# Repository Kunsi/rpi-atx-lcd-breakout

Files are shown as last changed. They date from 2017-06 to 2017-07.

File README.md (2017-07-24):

# RPi-ATX-LCD-Breakout

This board allows you to connect an ATX power supply and a HD44780-compatible LCD
screen to your Raspberry Pi (or others with compatible GPIO layout).

While it does have a 40pin GPIO connector, it will also work with older 
26-pin variants of the Pi.

The board was created to provide a convenient interface for two
[Octoprint](http://octoprint.org/) plugins:
[PSUControl](https://github.com/kantlivelong/OctoPrint-PSUControl) and
[LCD-HD44780](https://github.com/Kunsi/Octoprint-LCD-HD44780) (See links on
bottom of this page).

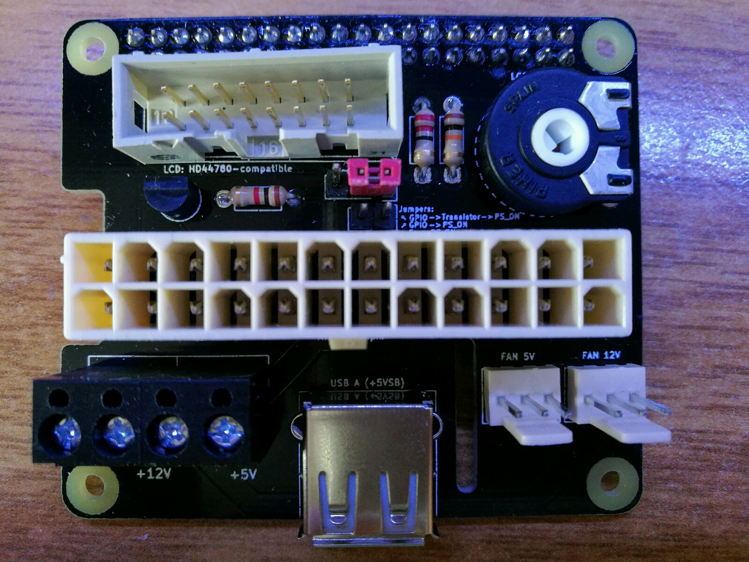
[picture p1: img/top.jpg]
Board


The board itself offers a variety of features:
* Powering the Pi using +5VSB (standby power)
* Switching the PSU on and off using GPIO pin 12
  
  The GPIO pin can be connected to PS_ON directly, or via a transistor. This is
  choosable using the three-pin jumper switch.

  Alternatively, the PSU can be forced to be on, by using the 2-pin PS_ON
  jumper.
* Providing a "is the PSU on"-detection by wiring GPIO pin 11 to the 3v3 rail
  of the PSU
* Connecting a character LCD to the Pi
  
  LCD is wired as follows:
  <dl>
    <dt>Register Select</dt>
    <dd>15</dd>

    <dt>Enable</dt>
    <dd>16</dd>

    <dt>Data 4</dt>
    <dd>21</dd>

    <dt>Data 5</dt>
    <dd>22</dd>

    <dt>Data 6</dt>
    <dd>23</dd>

    <dt>Data 7</dt>
    <dd>24</dd>
  </dl>

  Data 0-3 pins are not connected. Read/Write select has been wired to GND, so
  it's not possible to read data from the LCD screen. Contrast pin is
  connected to a potentiometer.
* Allow connecting of two fans, one 5V, one 12V
* Providing screw terminals for GND, +12V, +5VSB and +5V
* Providing a USB outlet powered by +5VSB

Note: All pin numbers use BOARD numbering.

## Cost
Prices are in Euro, and are based on my prototype production cost

Item            | Count    | Price | Link
----------------|---------:|------:|---
PCB             | 1        | 1.70  | [PCBway](https://www.pcbway.com/) got me 10 boards for 17$
Fan connector   | 2        | 0.42  | <https://www.reichelt.de/?ARTICLE=185658>
Pin header      | 3+2 wide | 0.09  | <https://www.reichelt.de/?ARTICLE=119891>
Potentiometer   | 1        | 0.38  | <https://www.reichelt.de/?ARTICLE=14951>
LCD connector   | 1        | 0.52  | <https://www.reichelt.de/?ARTICLE=175351>
Screw terminals | 2        | 0.42  | <https://www.reichelt.de/?ARTICLE=170222>
Jumper          | 1        | 0.03  | <https://www.reichelt.de/?ARTICLE=119944>
USB connector   | 1        | 0.20  | <https://www.reichelt.de/?ARTICLE=22184>
Transistor      | 1        | 0.09  | <https://www.reichelt.de/?ARTICLE=1999>
Resistors       | 1+1+1    | 0.30  | <https://www.reichelt.de/?ARTICLE=1381><br> <https://www.reichelt.de/?ARTICLE=1315><br> <https://www.reichelt.de/?ARTICLE=1338>
GPIO connector  | 1        | 0.11  | [https://de.aliexpress.com/…/32454935478.html](https://de.aliexpress.com/item/100pcs-lot-2-54mm-Double-Row-Female-12P-Straight-Header-Pitch-Socket-Strip-2X20-Pin/32454935478.html)
ATX connector   | 1        | 0.43  | <http://www.mouser.de/ProductDetail/TE-Connectivity/1-1775099-3/>

## Links
* [Octoprint](http://octoprint.org/)
* [OctoPrint-PSUControl](https://github.com/kantlivelong/OctoPrint-PSUControl) by kantlivelong
* [Octoprint-LCD-HD44780](https://github.com/Kunsi/Octoprint-LCD-HD44780) by Kunsi

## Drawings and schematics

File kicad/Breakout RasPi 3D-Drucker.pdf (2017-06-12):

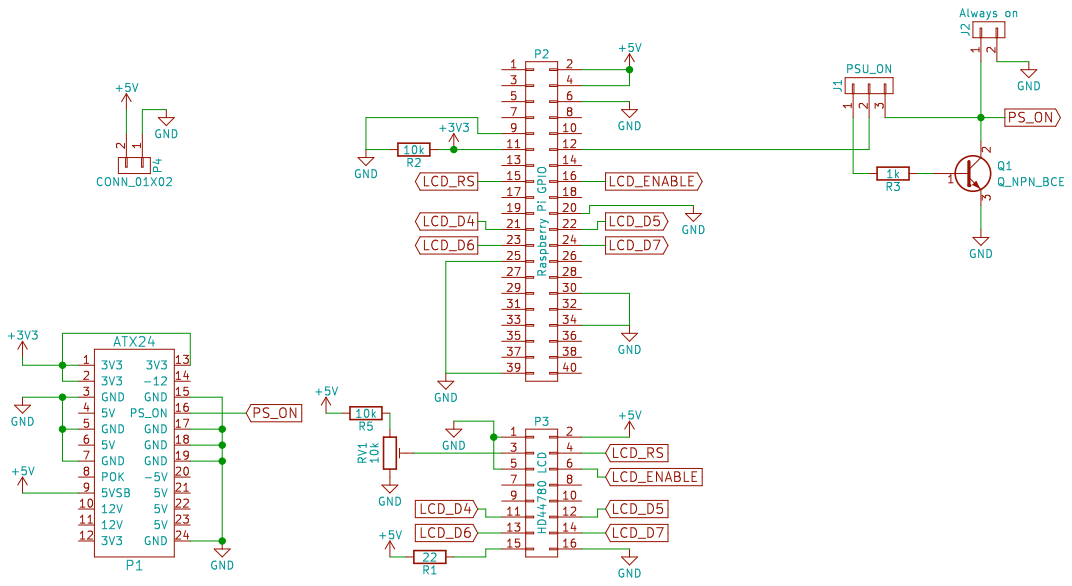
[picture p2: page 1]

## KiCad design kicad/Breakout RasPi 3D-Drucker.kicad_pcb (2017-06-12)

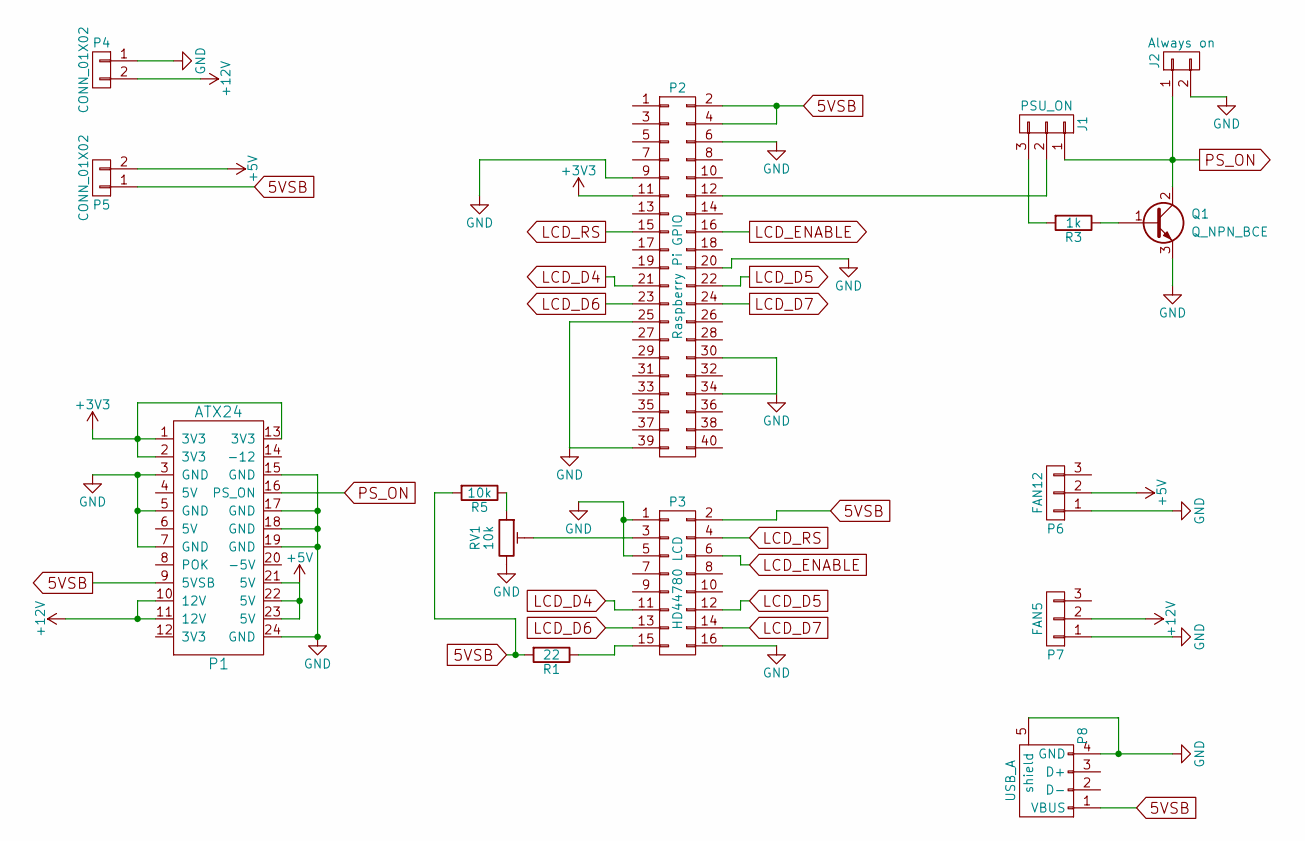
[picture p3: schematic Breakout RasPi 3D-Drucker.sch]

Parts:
J1: PSU_ON; Pin_Header_Straight_1x03
J2: Always on; Pin_Header_Straight_1x02
P1: ATX24
P2: Raspberry Pi GPIO; Socket_Strip_Straight_2x20
P3: HD44780 LCD; IDC_Header_Straight_16pins
P4, P5: CONN_01X02; RND_205-00001
P6: FAN12; Molex_KK-6410-03_03x2.54mm_Straight
P7: FAN5; Molex_KK-6410-03_03x2.54mm_Straight
P8: USB_A
Q1: Q_NPN_BCE; TO-92_Inline_Narrow_Oval
R1: 22; Resistor_Horizontal_RM7mm
R3: 1k; Resistor_Horizontal_RM7mm
R5: 10k; Resistor_Horizontal_RM7mm
RV1: 10k; Potentiometer_Trimmer-Piher_PT15-V12-5_horizontal_revers

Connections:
5VSB: P1.9 (5VSB), P2.2, P2.4, P3.2, P5.1, P8.1 (VBUS), R1.2, R5.2
+3V3: P1.1 (3V3), P1.2 (3V3), P1.13 (3V3), P2.11
+5V: P1.21 (5V), P1.22 (5V), P1.23 (5V), P5.2, P6.2
+12V: P1.10 (12V), P1.11 (12V), P4.2, P7.2
GND: J2.2, P1.3 (GND), P1.5 (GND), P1.7 (GND), P1.15 (GND), P1.17 (GND), P1.18 (GND), P1.19 (GND), P1.24 (GND), P2.6, P2.9, P2.20, P2.25, P2.30, P2.34, P2.39, P3.1, P3.5, P3.16, P4.1, P6.1, P7.1, P8.4 (GND), P8.5 (shield), Q1.3 (E), RV1.3
LCD_D4: P2.21, P3.11
LCD_D5: P2.22, P3.12
LCD_D6: P2.23, P3.13
LCD_D7: P2.24, P3.14
LCD_ENABLE: P2.16, P3.6
LCD_RS: P2.15, P3.4
unnamed: J1.2, P2.12
unnamed: J1.3, R3.2
unnamed: P3.3, RV1.2
unnamed: P3.15, R1.1
unnamed: Q1.1 (B), R3.1
unnamed: R5.1, RV1.1
PS_ON: J1.1, J2.1, P1.16 (PS_ON), Q1.2 (C)

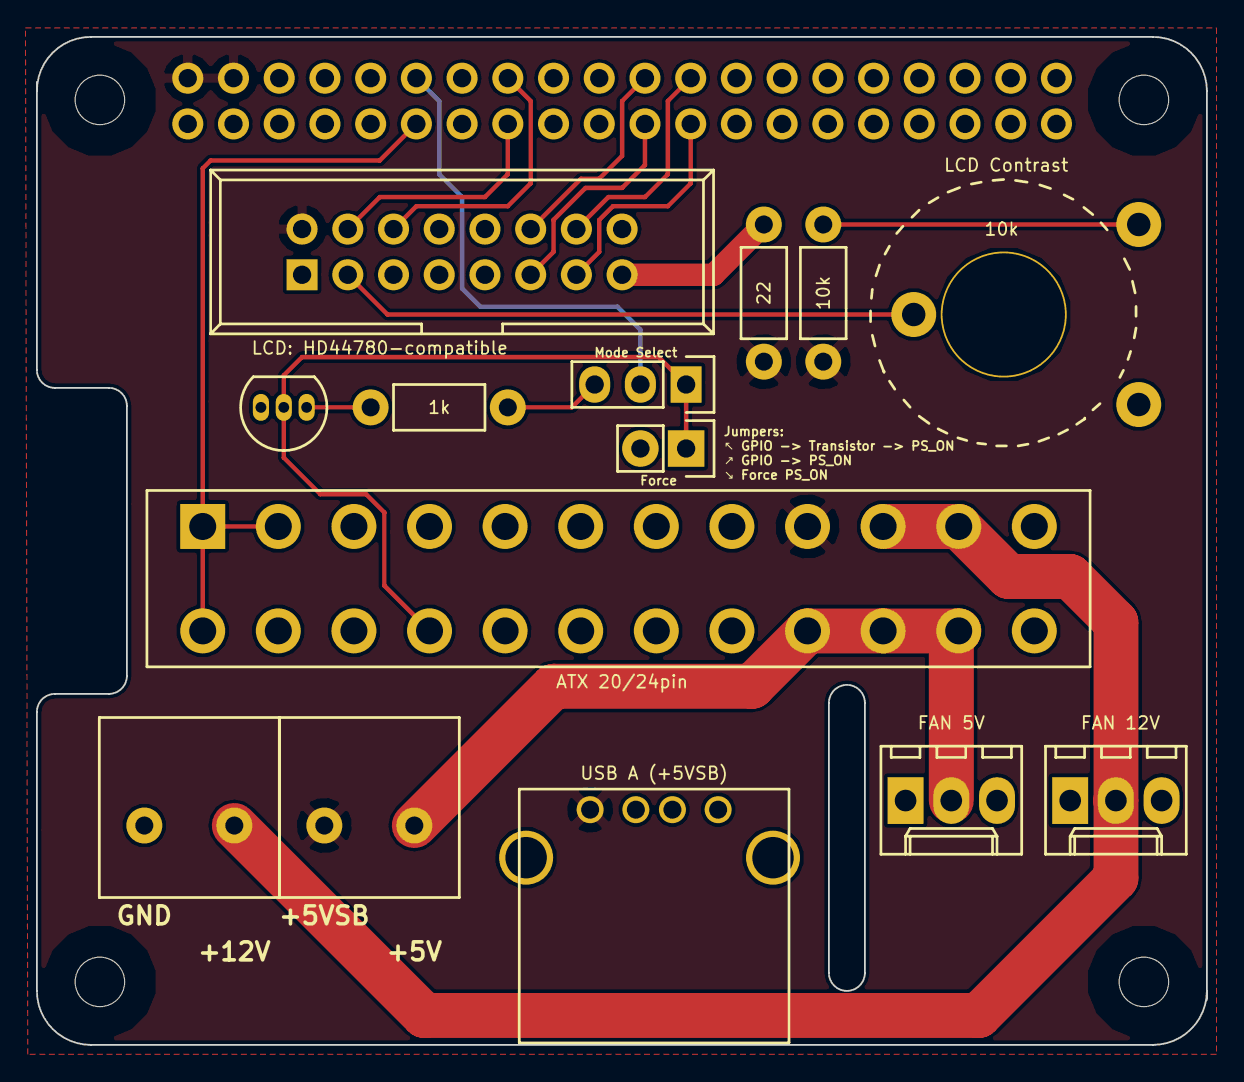
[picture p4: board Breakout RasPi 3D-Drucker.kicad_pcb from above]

Board: 2 copper layers, 65.0 x 56.0 mm, 15 parts (1 on the bottom side), 18 nets.

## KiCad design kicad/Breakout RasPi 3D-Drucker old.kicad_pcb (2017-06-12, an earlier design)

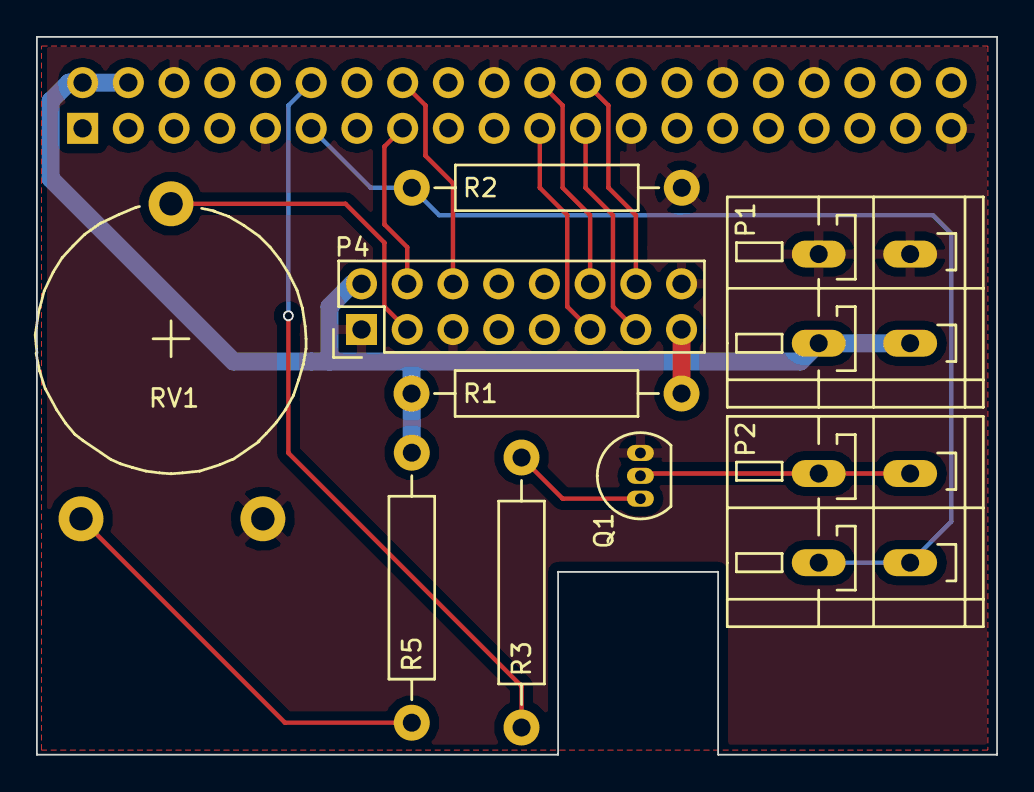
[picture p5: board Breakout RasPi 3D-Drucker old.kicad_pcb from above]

Board: 2 copper layers, 53.3 x 39.9 mm, 10 parts (1 on the bottom side), 15 nets.

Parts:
P1: Power; TerminalBlock_WAGO-236_2Stift_RM5mm_2pol
P2: PSU_Control; TerminalBlock_WAGO-236_2Stift_RM5mm_2pol
P3: Raspberry Pi GPIO; Socket_Strip_Straight_2x20
P4: HD44780 LCD; Pin_Header_Straight_2x08
Q1: Q_NPN_BCE; TO-92_Inline_Narrow_Oval
R1: 22; Resistor_Horizontal_RM15mm
R2, R5: 10k; Resistor_Horizontal_RM15mm
R3: 1k; Resistor_Horizontal_RM15mm
RV1: 10k; Potentiometer_Trimmer-Piher_PT15-V17-5_horizontal

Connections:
+3V3: P2.1, P3.11, R2.1
+5V: P1.1, P3.2, P3.4, P4.2, R1.2, R5.2
GND: P1.2, P3.6, P3.9, P3.20, P3.25, P3.30, P3.34, P3.39, P4.1, P4.5, P4.16, Q1.3, R2.2, RV1.3
LCD_D4: P3.21, P4.11
LCD_D5: P3.22, P4.12
LCD_D6: P3.23, P4.13
LCD_D7: P3.24, P4.14
LCD_ENABLE: P3.16, P4.6
LCD_RS: P3.15, P4.4
unnamed: P3.12, R3.2
unnamed: P4.3, RV1.2
unnamed: P4.15, R1.1
unnamed: Q1.1, R3.1
unnamed: R5.1, RV1.1
PS_ON: P2.2, Q1.2

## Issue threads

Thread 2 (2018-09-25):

Potential display corruption

sbts, 2018-09-25:
Due to the potentially long cable lengths people may use, induced noise on the power supply and data/control lines may cause occasional data corruption on the display.

To assist in mitigation adding a 1uF electrolytic and 0.2uF monolithic across the supply pins feeding the display may be beneficial.
Adding space.for these on the PCB is desirable.

If the above isn't adequate doing one or more of the following may have further benefit.
- add the same pair of capacitors at the display it's self
- fit 5pF to 50pF between each data/control pin and ground at the breakout board
- fit 5pF to 50pF between each data/control pin and ground at the display

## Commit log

2017-06-12 Add cost of PCB and parts
2017-06-14 README: Add Info about pin 11 (3V3 in)
